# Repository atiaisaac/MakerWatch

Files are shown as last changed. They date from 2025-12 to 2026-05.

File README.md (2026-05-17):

# MakerWatch
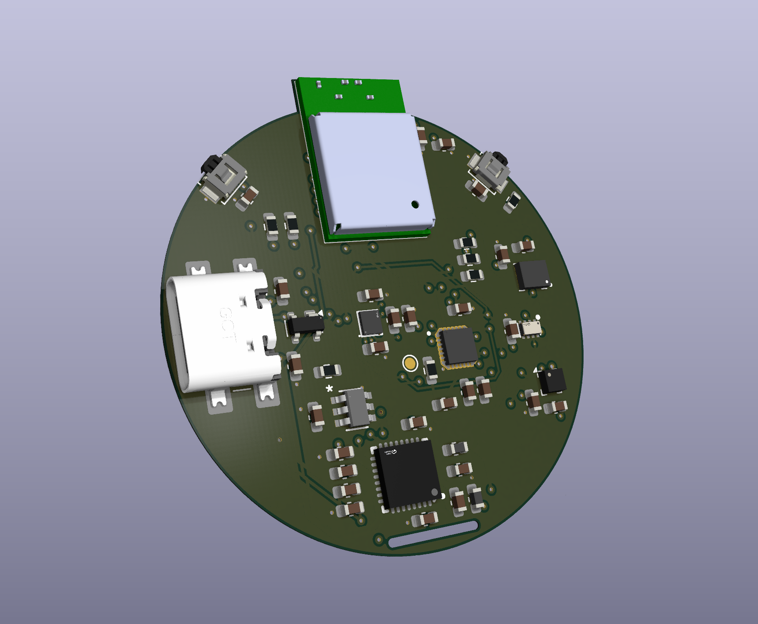
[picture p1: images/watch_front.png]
Main board


## About
An open source smartwatch built by a maker for the maker community packed with interesting features and runs on the zephry RTOS

## Hardware
Outlined below is a breakdown of the hardware componenets considered for this design;

* __NINA-B306__ module (nrf52840 based microcontroller)
    * 1MB flash memory
    * 256KB of RAM
    * Bluetooth LE
    * internal pcb antenna
* __LSM6DSOX__ IMU with 6-DOF from stmicroelectronics. Primarily for step counting (pedometer) and other cool navigation gestures.
* __NPM1300__ single cell li-ion charger with power path managament. It also includes 2 buck converters capable of providing 200mA each and 3 LDOs. More than enough for our setup. When paired with the right nrf chipset, it can serve as a fuel guage as well.
* __MAX86141__ an AFE for optical data acquisition. Paired with MAX32664
* __MAX32664__ an ultra-low power biometric sensor hub with embedded firmware for heart rate monitoring and blood oxygen saturation measurement.
* __KX122__ paired with MAX32664 to compensate for artifacts of motion required for proper HRM and SpO2 measurement.
* __FIREFLY E2218__ true green color for health monitoring i.e HRM and pulse oximetry
* __SFH 7015__ hyper-red and infrared for HRM and pulse oximetry.
* __SFH 2703__ is a photodiode for capturing reflected light needed by the HRM and SpO2 algorithm
* 1.28'' round tft display with __GC9a01__ display driver
* __RV-8263-C8__ crystal to serve as real time clock/calendar
* __USB-C__ interface for easy flashing of firmware for developers/makers

The hardware setup is made up of two board stacked together back to back my a mezzinine connector. There is the main watch board and what I have dubbed the ppg board that has the leds for photoplethysemography.
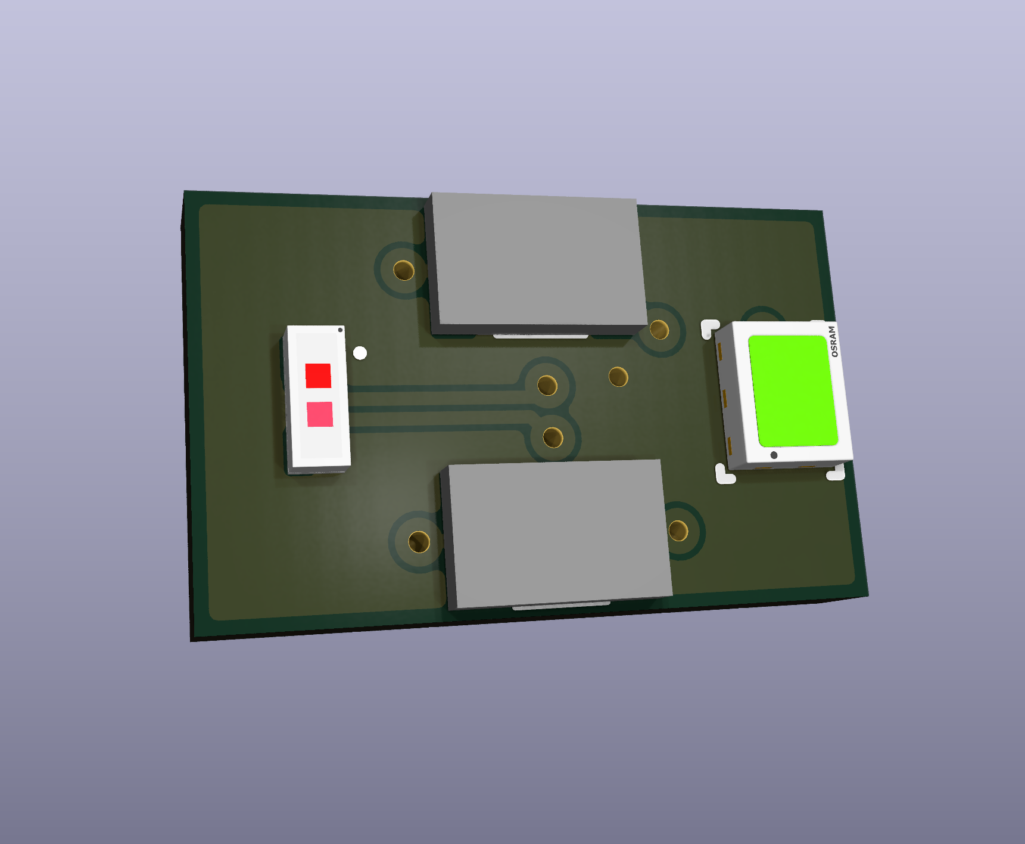
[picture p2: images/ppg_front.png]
PPG board


## Software
The MakerWatch uses a usb-c as the main source of flashing new firmware. However, on the board, there are breakout pads that serve as Serial Wire Debug (SWD) interface for doing other cool stuff like ITM when paired with the right hardware programmer. In this version, wires will have to be soldered onto the pads before use.

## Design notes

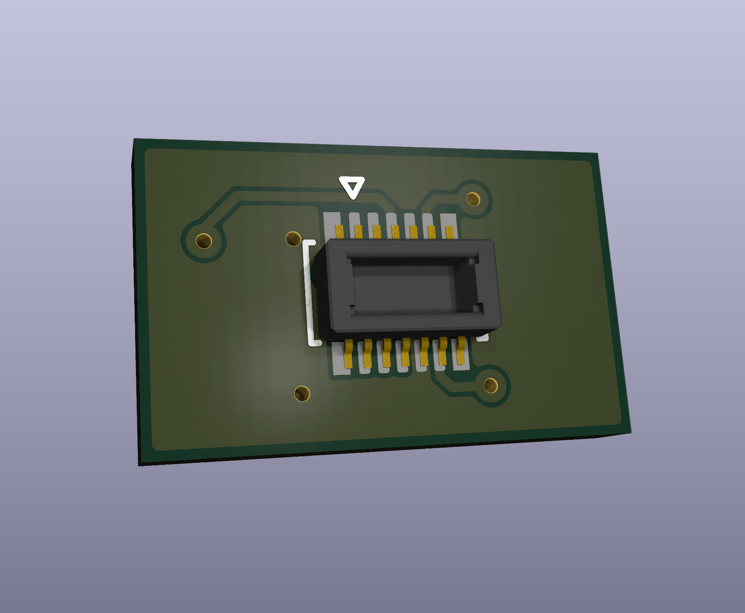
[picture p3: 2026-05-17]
images/ppg_back.png

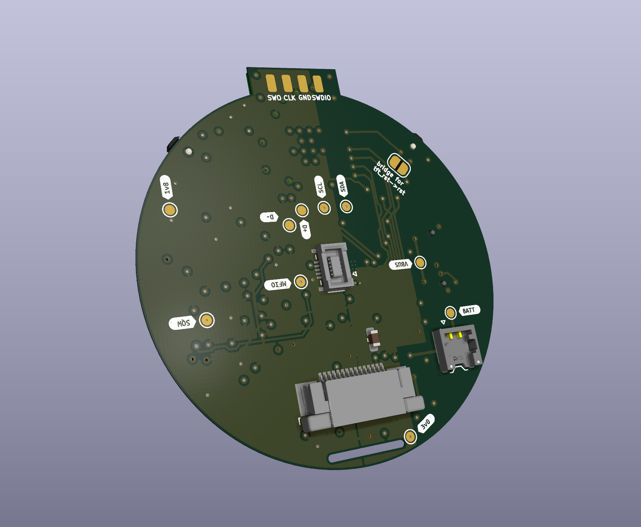
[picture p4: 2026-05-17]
images/watch_back.png

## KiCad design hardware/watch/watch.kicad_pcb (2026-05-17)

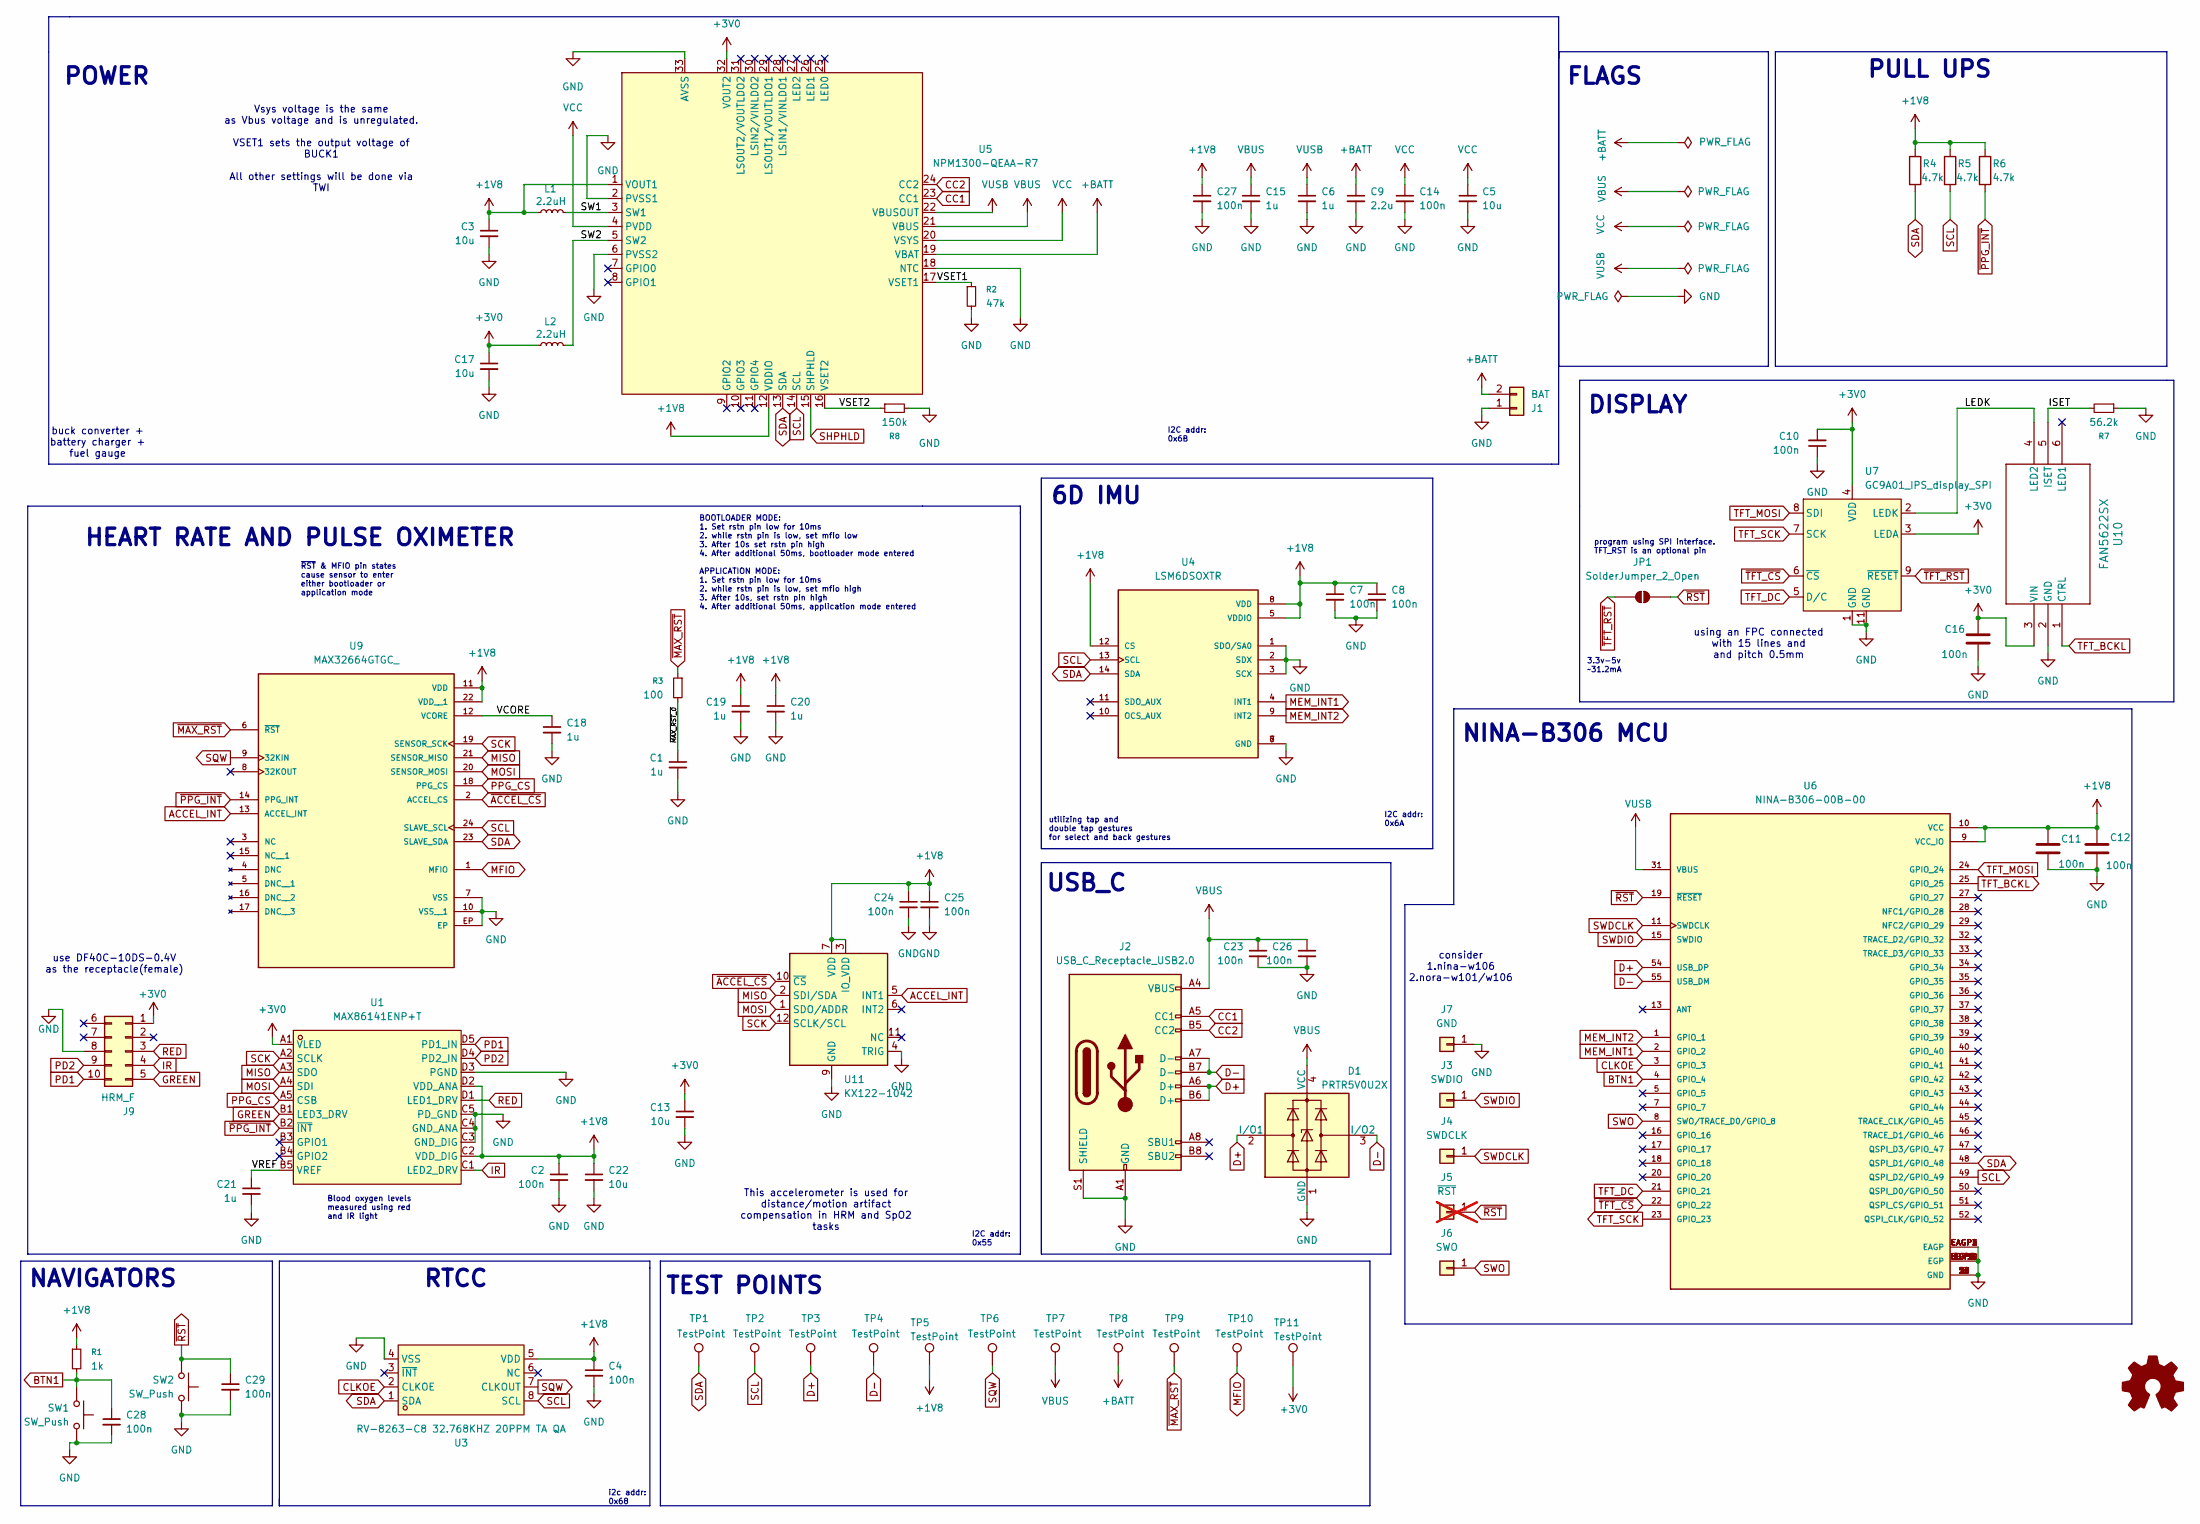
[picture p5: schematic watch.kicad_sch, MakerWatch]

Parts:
C1, C6, C15, C18, C19, C20, C21: 1u; C_0603_1608Metric
C2, C4, C7, C8, C10, C11, C12, C14, C16, C23, C24, C25, C26, C27, C28, C29: 100n; C_0603_1608Metric
C3, C5, C13, C17, C22: 10u; C_0603_1608Metric
C9: 2.2u; C_0603_1608Metric
D1: PRTR5V0U2X; SOT-143
J1: BAT; JST_ACH_BM02B-ACHSS-GAN-ETF_1x02-1MP_P1.20mm_Vertical
J2: USB_C_Receptacle_USB2.0; USB_C_Receptacle_GCT_USB4110; LCSC Part C3039307
J3: SWDIO; SolderWirePad_1x01_SMD_1x2mm
J4: SWDCLK; SolderWirePad_1x01_SMD_1x2mm
J5: ~{RST}; SolderWirePad_1x01_SMD_1x2mm; not fitted
J6: SWO; SolderWirePad_1x01_SMD_1x2mm
J7: GND; SolderWirePad_1x01_SMD_1x2mm
J9: HRM_F; Hirose_DF40B-10DS-0.4V_2x05-1MP_P0.4mm
JP1: SolderJumper_2_Open; SolderJumper-2_P1.3mm_Open_RoundedPad1.0x1.5mm
L1, L2: 2.2uH; L_0603_1608Metric
R1: 1k; R_0603_1608Metric
R2: 47k; R_0603_1608Metric
R3: 100; R_0603_1608Metric
R4, R5, R6: 4.7k; R_0603_1608Metric
R7: 56.2k; R_0603_1608Metric
R8: 150k; R_0603_1608Metric
SW1, SW2: SW_Push; SW_SPST_B3U-3000P-B; lcsc part C963349
TP1, TP2, TP3, TP4, TP5, TP6, TP7, TP8, TP9, TP10, TP11: TestPoint; TestPoint_Pad_D1.0mm
U1: MAX86141ENP+T; BGA-20_L2.0-W1.8-R4-C5-P0.40-TL; LCSC Part C5328762
U3: RV-8263-C8 32.768KHZ 20PPM TA QA; OSC-SMD_8P-L2.0-W1.2; LCSC Part C24955829
U4: LSM6DSOXTR; PQFN50P250X300X86-14N; PARTREV 3.0
U5: NPM1300-QEAA-R7; QFN-32_L5.0-W5.0-P0.50-TL-EP3.5; LCSC Part C7501206
U6: NINA-B306-00B-00; XCVR_NINA-B306-00B-00; PARTREV R07
U7: GC9A01_IPS_display_SPI; 15p_tft_P0.5; LCSC Part C262209
U9: MAX32664GTGC_; IC_MAX32664GTGC_; PARTREV 4
U10: FAN5622SX; SSOT6_3X1P7_ONS
U11: KX122-1042; LGA-12_2x2mm_P0.5mm

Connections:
+1V8: C2.1, C3.1, C4.1, C7.1, C8.1, C11.1, C12.1, C19.1, C20.1, C22.1, C24.1, C25.1, C27.1, L1.1, R1.1, R4.1, R5.1, R6.1, TP5.1 (1_1), U1.C2 (VDD_DIG), U1.D2 (VDD_ANA), U3.5 (VDD), U4.5 (VDDIO), U4.8 (VDD), U4.12 (CS), U5.1 (VOUT1), U5.12 (VDDIO), U6.9 (VCC_IO), U6.10 (VCC), U9.11 (VDD), U9.22 (VDD__1), U11.3 (IO_VDD), U11.7 (VDD)
+3V0: C10.2, C13.1, C16.1, C17.1, J9.1, L2.1, TP11.1 (1_1), U1.A1 (VLED), U5.32 (VOUT2), U7.3 (LEDA), U7.4 (VDD), U10.3 (VIN)
+BATT: C9.1, J1.2, TP8.1 (1_1), U5.19 (VBAT)
/ISET: R7.2, U10.5 (ISET)
/LEDK: U7.2 (LEDK), U10.4 (LED2)
/SW1: L1.2, U5.3 (SW1)
/SW2: L2.2, U5.5 (SW2)
/VCORE: C18.1, U9.12 (VCORE)
/VREF: C21.1, U1.B5 (VREF)
/VSET1: R2.1, U5.17 (VSET1)
/VSET2: R8.1, U5.16 (VSET2)
/~MAX_RST_0: C1.1, R3.2
ACCEL_INT: U9.13 (ACCEL_INT), U11.5 (INT1)
BTN1: C28.1, R1.2, SW1.2, U6.4 (GPIO_4)
CC1: J2.A5 (CC1), U5.23 (CC1)
CC2: J2.B5 (CC2), U5.24 (CC2)
CLKOE: U3.2 (CLKOE), U6.3 (GPIO_3)
D+: D1.2 (I/O1), J2.A6 (D+), J2.B6 (D+), TP3.1 (1_1), U6.54 (USB_DP)
D-: D1.3 (I/O2), J2.A7 (D-), J2.B7 (D-), TP4.1 (1_1), U6.55 (USB_DM)
GND: C1.2, C2.2, C3.2, C4.2, C5.2, C6.2, C7.2, C8.2, C9.2, C10.1, C11.2, C12.2, C13.2, C14.2, C15.2, C16.2, C17.2, C18.2, C19.2, C20.2, C21.2, C22.2, C23.2, C24.2, C25.2, C26.2, C27.2, C28.2, C29.2, D1.1 (GND), J1.1, J2.A1 (GND), J2.A12 (GND), J2.B1 (GND), J2.B12 (GND), J2.S1 (SHIELD), J7.1 (Pin_1_1), J9.8, R2.2, R7.1, R8.2, SW1.1, SW2.1, U1.C3 (GND_DIG), U1.C4 (GND_ANA), U1.C5 (PD_GND), U1.D3 (PGND), U3.4 (VSS), U4.1 (SDO/SA0), U4.2 (SDX), U4.3 (SCX), U4.6 (GND), U4.7 (GND), U5.2 (PVSS1), U5.6 (PVSS2), U5.18 (NTC), U5.33 (AVSS), U6.6 (GND), U6.12 (GND), U6.14 (GND), U6.26 (GND), U6.30 (GND), U6.53 (GND), U6.EAGP1 (EAGP), U6.EAGP2 (EAGP), U6.EAGP3 (EAGP), U6.EAGP4 (EAGP), U6.EGP1 (EGP), U6.EGP2 (EGP), U6.EGP3 (EGP), U6.EGP4 (EGP), U6.EGP5 (EGP), U6.EGP6 (EGP), U6.EGP7 (EGP), U6.EGP8 (EGP), U6.EGP9 (EGP), U6.EGP10 (EGP), U6.EGP11 (EGP), U6.EGP12 (EGP), U7.1 (GND), U7.11 (GND), U9.7 (VSS), U9.10 (VSS__1), U9.EP, U10.2 (GND), U11.4 (TRIG), U11.9 (GND)
GREEN: J9.5, U1.B1 (LED3_DRV)
IR: J9.4, U1.C1 (LED2_DRV)
MEM_INT1: U4.4 (INT1), U6.2 (GPIO_2)
MEM_INT2: U4.9 (INT2), U6.1 (GPIO_1)
MFIO: TP10.1 (1_1), U9.1 (MFIO)
MISO: U1.A3 (SDO), U9.21 (SENSOR_MISO), U11.2 (SDI/SDA)
MOSI: U1.A4 (SDI), U9.20 (SENSOR_MOSI), U11.1 (SDO/ADDR)
PD1: J9.10, U1.D5 (PD1_IN)
PD2: J9.9, U1.D4 (PD2_IN)
PPG_CS: U1.A5 (CSB), U9.18 (PPG_CS)
RED: J9.3, U1.D1 (LED1_DRV)
SCK: U1.A2 (SCLK), U9.19 (SENSOR_SCK), U11.12 (SCLK/SCL)
SCL: R5.2, TP2.1 (1_1), U3.8 (SCL), U4.13 (SCL), U5.14 (SCL), U6.49 (QSPI_D2/GPIO_49), U9.24 (SLAVE_SCL)
SDA: R4.2, TP1.1 (1_1), U3.1 (SDA), U4.14 (SDA), U5.13 (SDA), U6.48 (QSPI_D1/GPIO_48), U9.23 (SLAVE_SDA)
SHPHLD: U5.15 (SHPHLD)
SQW: TP6.1 (1_1), U3.7 (CLKOUT), U9.9 (32KIN)
SWDCLK: J4.1 (Pin_1_1), U6.11 (SWDCLK)
SWDIO: J3.1 (Pin_1_1), U6.15 (SWDIO)
SWO: J6.1 (Pin_1_1), U6.8 (SWO/TRACE_D0/GPIO_8)
TFT_BCKL: U6.25 (GPIO_25), U10.1 (CTRL)
TFT_DC: U6.21 (GPIO_21), U7.5 (D/C)
TFT_MOSI: U6.24 (GPIO_24), U7.8 (SDI)
TFT_SCK: U6.23 (GPIO_23), U7.7 (SCK)
VBUS: C15.1, C23.1, C26.1, D1.4 (VCC), J2.A4 (VBUS), J2.A9 (VBUS), J2.B4 (VBUS), J2.B9 (VBUS), TP7.1 (1_1), U5.21 (VBUS)
VCC: C5.1, C14.1, U5.4 (PVDD), U5.20 (VSYS)
VUSB: C6.1, U5.22 (VBUSOUT), U6.31 (VBUS)
~ACCEL_CS: U9.2 (ACCEL_CS), U11.10 (~CS)
~MAX_RST: R3.1, TP9.1 (1_1), U9.6 (~RST)
~PPG_INT: R6.2, U1.B2 (~INT), U9.14 (PPG_INT)
~RST: C29.1, J5.1, JP1.2 (B), SW2.2, U6.19 (~RESET)
~TFT_CS: U6.22 (GPIO_22), U7.6 (~CS)
~TFT_RST: JP1.1 (A), U7.9 (~RESET)

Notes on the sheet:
~{RST} & MFIO pin states cause sensor to enter either bootloader or application mode
Vsys voltage is the same as Vbus voltage and is unregulated. VSET1 sets the output voltage of BUCK1 All other settings will be done via TWI
NAVIGATORS
FLAGS
I2C addr: 0x6B
This accelerometer is used for distance/motion artifact compensation in HRM and SpO2 tasks
Blood oxygen levels measured using red and IR light
NINA-B306 MCU
using an FPC connected with 15 lines and and pitch 0.5mm
I2C addr: 0x55
POWER
use DF40C-10DS-0.4V as the receptacle(female)
i2c addr: 0x68
BOOTLOADER MODE: 1. Set rstn pin low for 10ms 2. while rstn pin is low, set mfio low 3. After 10s set rstn pin high 4. After additional 50ms, bootloader mode entered APPLICATION MODE: 1. Set rstn pin low for 10ms 2. while rstn pin is low, set mfio high 3. After 10s, set rstn pin high 4. After addit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
consider 1.nina-w106 2.nora-w101/w106
buck converter + battery charger + fuel gauge
USB_C
program using SPI interface. TFT_RST is an optional pin
PULL UPS
6D IMU
utilizing tap and double tap gestures for select and back gestures
3.3v-5v ~31.2mA
DISPLAY
TEST POINTS
HEART RATE AND PULSE OXIMETER
I2C addr: 0x6A
RTCC

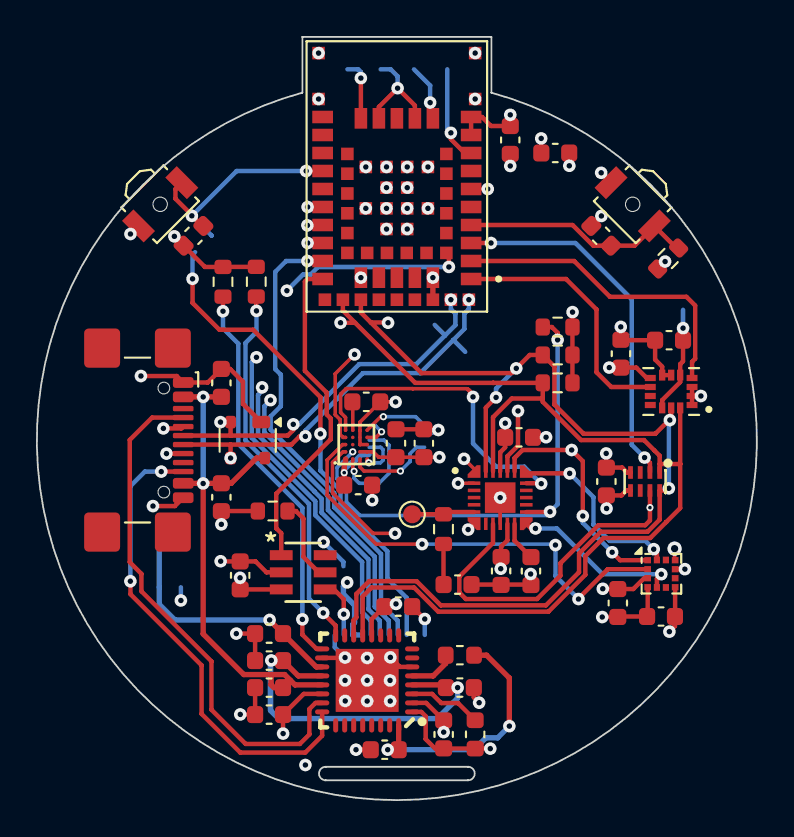
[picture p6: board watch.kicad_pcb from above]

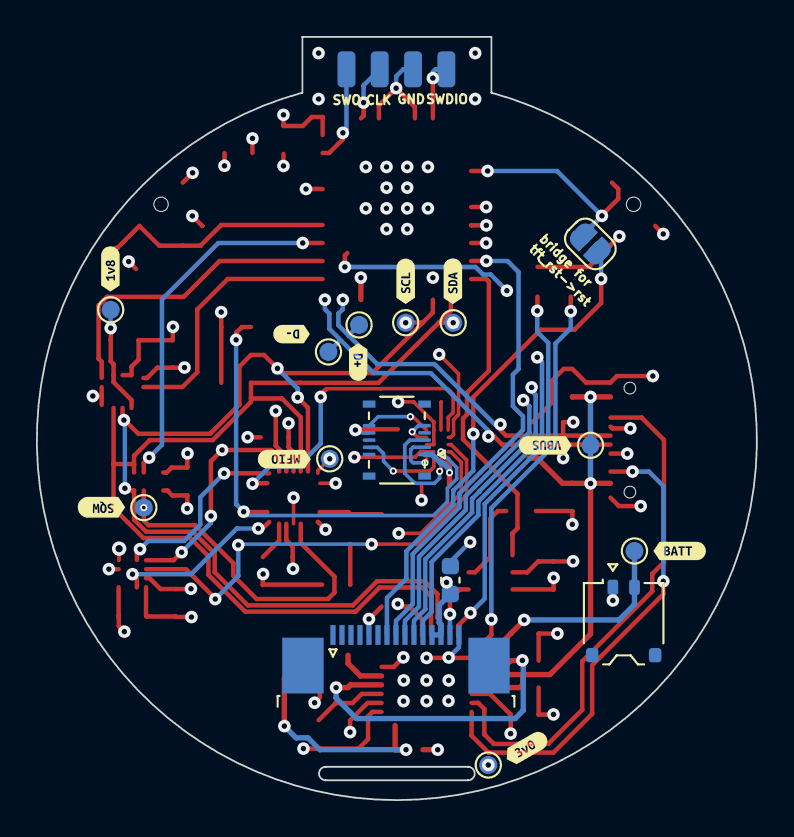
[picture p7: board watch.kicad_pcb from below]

Board: 4 copper layers, 40.0 x 42.4 mm, 80 parts (29 on the bottom side), 51 nets.

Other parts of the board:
kibuzzard-6A0A16D4: G***; kibuzzard-6A0A16D4
kibuzzard-6A0A1465: G***; kibuzzard-6A0A1465
kibuzzard-6A08DFE9: G***; kibuzzard-6A08DFE9
kibuzzard-6A08DFFD: G***; kibuzzard-6A08DFFD
kibuzzard-6A08E0DD: G***; kibuzzard-6A08E0DD
kibuzzard-6A08E0EE: G***; kibuzzard-6A08E0EE
kibuzzard-6A08E02E: G***; kibuzzard-6A08E02E
kibuzzard-6A08E019: G***; kibuzzard-6A08E019
kibuzzard-6A08E080: G***; kibuzzard-6A08E080
kibuzzard-6A08E121: G***; kibuzzard-6A08E121

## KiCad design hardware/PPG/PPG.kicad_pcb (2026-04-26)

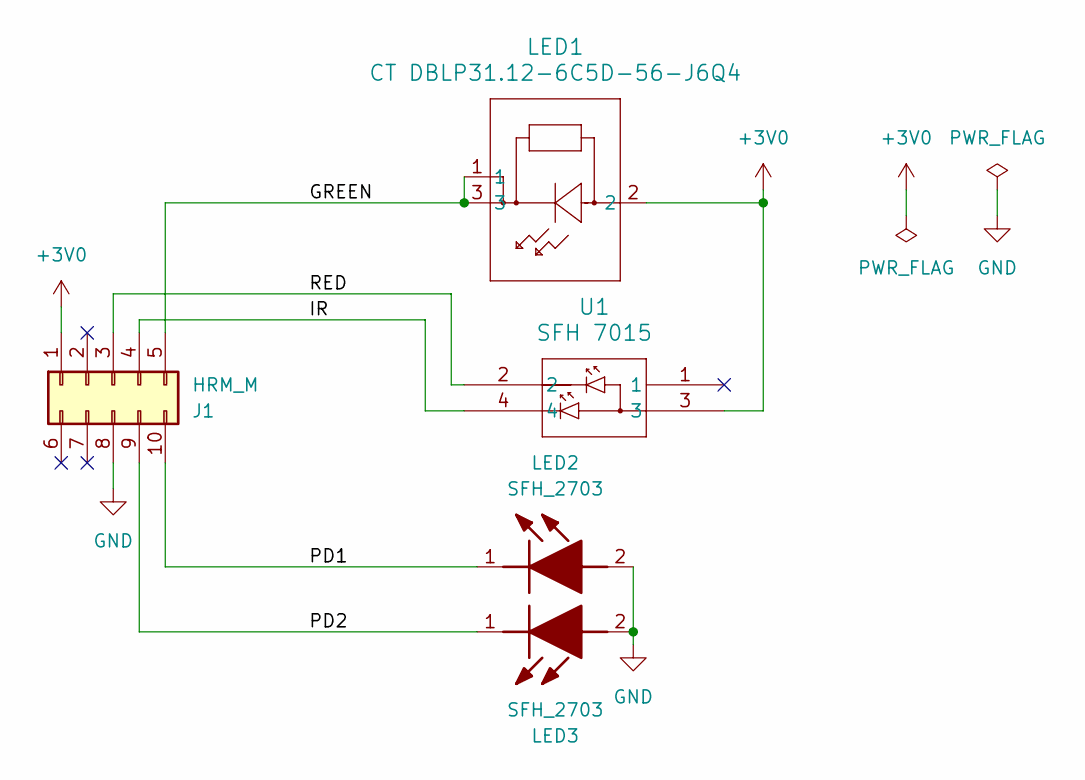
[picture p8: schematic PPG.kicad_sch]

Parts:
J1: HRM_M; Hirose_DF40C-10DP-0.4V_2x05-1MP_P0.4mm
LED1: CT DBLP31.12-6C5D-56-J6Q4; CT DBLP31.12-6C5D-56-J6Q4_OSR
LED2, LED3: SFH_2703; SFH2703; Mouser Part Number 720-SFH2703
U1: SFH 7015; SFH7015

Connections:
+3V0: J1.1, LED1.2, U1.3
/GREEN: J1.5, LED1.1, LED1.3
/IR: J1.4, U1.4
/PD1: J1.10, LED2.1 (K)
/PD2: J1.9, LED3.1 (K)
/RED: J1.3, U1.2
GND: J1.8, LED2.2 (A), LED3.2 (A)

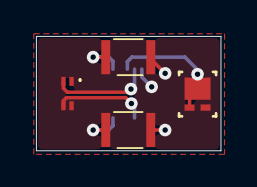
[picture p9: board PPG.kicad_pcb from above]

Board: 2 copper layers, 10.2 x 6.3 mm, 5 parts (1 on the bottom side), 7 nets.

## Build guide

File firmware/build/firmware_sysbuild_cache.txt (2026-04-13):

APPLICATION_BINARY_DIR:PATH=/home/atia/Documents/watch_project/firmware/build
APPLICATION_SOURCE_DIR:PATH=/home/atia/ncs/v3.2.1/zephyr/share/sysbuild/template
APP_DIR:PATH=/home/atia/Documents/watch_project/firmware
BOARD_DIR:PATH=/home/atia/Documents/watch_project/firmware/boards/sw/ninab306
BOARD_DIRECTORIES:INTERNAL=/home/atia/Documents/watch_project/firmware/boards/sw/ninab306
BOARD_EXTENSIONS:BOOL=ON
BOARD_ROOT:PATH=/home/atia/Documents/watch_project/firmware
CACHED_BOARD:STRING=ninab306/nrf52840
CACHED_SHIELD:STRING=
CACHED_SNIPPET:STRING=
CONF_FILE:UNINITIALIZED=prj.conf
DTC_OVERLAY_FILE:UNINITIALIZED=boards/sw/ninab306/ninab306.overlay
FIND_PACKAGE_MESSAGE_DETAILS_Python3:INTERNAL=[/home/atia/ncs/toolchains/43683a87ea/usr/local/bin/python3.12][cfound components: Interpreter ][v3.12.4(3.10)]
HWM:INTERNAL=v2
HWMv2:INTERNAL=True
WEST:INTERNAL=/home/atia/ncs/toolchains/43683a87ea/usr/local/bin/python3.12;-m;west
WEST_PYTHON:UNINITIALIZED=/home/atia/ncs/toolchains/43683a87ea/usr/local/bin/python3.12
ZEPHYR_BASE:PATH=/home/atia/ncs/v3.2.1/zephyr
ZEPHYR_RUNNER_CONFIG_KERNEL_HEX:STRING=
Zephyr_DIR:PATH=/home/atia/ncs/v3.2.1/zephyr/share/zephyr-package/cmake
_Python3_EXECUTABLE:INTERNAL=/home/atia/ncs/toolchains/43683a87ea/usr/local/bin/python3.12
_Python3_INTERPRETER_PROPERTIES:INTERNAL=Python;3;12;4;64;;cpython-312-x86_64-linux-gnu;/home/atia/ncs/toolchains/43683a87ea/usr/local/lib/python3.12;/home/atia/ncs/toolchains/43683a87ea/usr/local/lib/python3.12;/home/atia/ncs/toolchains/43683a87ea/usr/local/lib/python3.12/site-packages;/home/atia/ncs/toolchains/43683a87ea/usr/local/lib/python3.12/site-packages
_Python3_INTERPRETER_SIGNATURE:INTERNAL=3a7ee629a0f37459750955077009dae3
firmware_NCS_RUNNER_HEX:INTERNAL=/home/atia/Documents/watch_project/firmware/build/merged.hex
sysbuild_BINARY_DIR:STATIC=/home/atia/Documents/watch_project/firmware/build/_sysbuild
sysbuild_IS_TOP_LEVEL:STATIC=OFF
sysbuild_SOURCE_DIR:STATIC=/home/atia/ncs/v3.2.1/zephyr/share/sysbuild/template
sysbuild_toplevel_BINARY_DIR:STATIC=/home/atia/Documents/watch_project/firmware/build
sysbuild_toplevel_IS_TOP_LEVEL:STATIC=ON
sysbuild_toplevel_SOURCE_DIR:STATIC=/home/atia/ncs/v3.2.1/zephyr/share/sysbuild
BOARD:STRING=ninab306/nrf52840
SYSBUILD_NAME:STRING=firmware
SYSBUILD_MAIN_APP:BOOL=True

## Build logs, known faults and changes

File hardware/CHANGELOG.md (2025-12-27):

# Hardware Changelog

## Unreleased

###

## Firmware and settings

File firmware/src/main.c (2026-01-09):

/*
 * Copyright (c) 2012-2014 Wind River Systems, Inc.
 *
 * SPDX-License-Identifier: Apache-2.0
 */

#include <stdio.h>
#include <zephyr/kernel.h>
#include <zephyr/device.h>
#include <zephyr/devicetree.h>
#include <zephyr/drivers/sensor.h>
#include <zephyr/drivers/gpio.h>
#include <zephyr/drivers/i2c.h>
#include <zephyr/drivers/spi.h>
#include <app_event_manager.h>

int main(void)
{
	printf("Hello World! %s\n", CONFIG_BOARD_TARGET);

	return 0;
}

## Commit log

2024-10-12 added kicad files
    [watch_designs.kicad_pcb, watch_designs.kicad_sch]
2024-11-07 Updated README.md to include display driver type
2025-07-01 updated design
    [watch_design_v2.kicad_pcb, watch_design_v2.kicad_sch]
2025-07-01 made design changes
    [watch_design_v2.kicad_pcb, watch_design_v2.kicad_sch]
2025-12-27 deleting all files
    [watch_design_v2.kicad_pcb, watch_design_v2.kicad_sch]
2025-12-27 restructured project files
    [watch_design_v2.kicad_pcb, watch_design_v2.kicad_sch]
2025-12-27 added kicad custom library as submodule
2025-12-27 updated design files with appropriate parts
    [watch_design_v2.kicad_sch]
2025-12-27 updated devicetree to include rtcc button
2026-01-09 restructured files
    [watch_design_v2.kicad_pcb, watch_design_v2.kicad_sch]
2026-04-13 updated design as a two part pcb
    [main_board.kicad_sch, ppg.kicad_sch, watch_design_v2.kicad_pcb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]
2026-04-19 updated design to include two boards connected back to back
    [main_board.kicad_sch, ppg.kicad_sch, watch_design_v2.kicad_pcb]
2026-04-26 two seperate projects for watch main board and ppg attachment
    [PPG.kicad_pcb, PPG.kicad_sch, main_board.kicad_sch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]
2026-05-17 updated designs
    [watch.kicad_pcb, watch.kicad_sch]
